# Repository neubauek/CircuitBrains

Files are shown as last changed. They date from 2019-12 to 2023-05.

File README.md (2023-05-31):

# CircuitBrains

## Deluxe
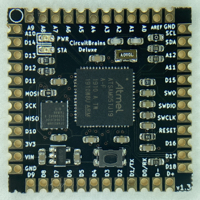
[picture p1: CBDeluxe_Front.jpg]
Deluxe Front
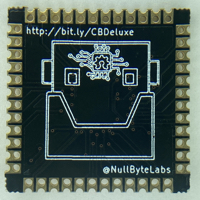
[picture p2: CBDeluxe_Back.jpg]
Deluxe Back
<br/>
https://kevinneubauer.com/projects/circuitbrains-deluxe/

Small form-factor 48-pin castellated pad module. Designed to allow an easy implementation of CircuitPython in maker/hacker projects without the bulk of a large breakout board.

Specs:
- Atmel ATSAMD51J19A Microcontroller (32-bit ARM Cortex M4)
- 8 MB SPI Flash
- Onboard 3.3V LDO Regulator
- Power and Status LEDs
- Breakouts for SPI and I2C
- Breakouts for 13 Analog and 19 Digital Inputs/Outputs

Revision History / Known Issues:

v1.0:
- Initial release
- Analog output does no work due to silicon issue with ATSAMD51. Requires a dedicated VREF/AREF pin with external 3.3 VREF input

v1.1 & v1.2:
- Not released due to issues resulting from design changes. I removed the pull-up on RST because the datasheet says it was optional. Turns out it was not so optional. These revisions will not function without a 10K resistor bodged onto the RST line.
- Dedicated a pin to VREF. Added a 0 Ohm resistor with a 3.3v input into VREF. 
- Switched from 4 layer to 2 layer board layout
- Rearranged layout to allow for pad documentation
- Added silkscreen for pad/pin assignments
- Added logo
- Removed inductor on VSW. Board will only work on linear power mode due to this.
- Removed polyfuse. Acceptable risk tradeoff for the space. If you want a fuse, add it to your design that incorporates this board.
- Removed Schottkey diode on VIN. Acceptable risk tradeoff for the space.
- Changed to a different flash chip with a smaller footprint
- Shuffled I/O pin assignments for more efficient trace routing/layout

v1.3:
- Added 10k pull-up back to RST.
- All tests working out: I2C, SPI, Analog & Digital In, Analog Out

## Basic
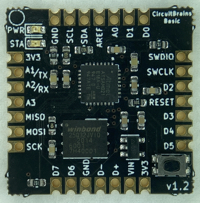
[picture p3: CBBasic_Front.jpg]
Basic Front
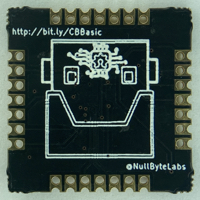
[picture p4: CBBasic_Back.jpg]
Basic Back
<br/>
https://kevinneubauer.com/projects/circuitbrains-basic/

Small form-factor 28-pin castellated pad module. Designed to allow an easy implementation of CircuitPython in maker/hacker projects without the bulk of a large breakout board.

Specs:
- Atmel ATSAMD21E18A Microcontroller (32-bit ARM Cortex M0)
- 4 MB SPI Flash
- Onboard 3.3V LDO Regulator
- Power and Status LEDs
- Breakouts for SPI and I2C
- Breakouts for 4 Analog and 8 Digital Inputs/Outputs

Revision History / Known Issues:
v1.2:
- Initial Release
- All tests working out

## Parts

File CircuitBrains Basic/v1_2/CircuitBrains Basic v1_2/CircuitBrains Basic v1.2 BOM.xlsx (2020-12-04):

Reference(s) | Value | Manufacturer | Part | Qty
C1, C4, C7 | 1uF | Yageo | CC0603KRX5R8BB105 | 3
C2, C3, C5, C6 | 0.1uF | Yageo | CC0603JRX7R9BB104 | 4
C8, C9 | 10uF | Murata | GRM188R61E106KA73D | 2
LED1 | GREEN | Würth Elektronik | 150060VS75000 | 1
LED2 | RED | Würth Elektronik | 150060RS75000 | 1
R1 | 100K | Yageo | RC0603FR-07100KL | 1
R3 | 330 | Yageo | RC0603FR-07330RL | 1
R4, R6 | 10K | Yageo | RC0603FR-0710KL | 2
R5, R7, R8 | 1K | Yageo | RC0603FR-071KL | 3
SW1 | KMR231 | C&K | KMR231NG LFS | 1
U1 | W25Q32JVZPIQ | Winbond Electronics | W25Q32JVZPIQ | 1
U2 | AP2112K-3.3 | Diodes Incorporated | AP2112K-3.3TRG1 | 1
U3 | ATSAMD21E18A-MU | Microchip Technology | ATSAMD21E18A-MU | 1

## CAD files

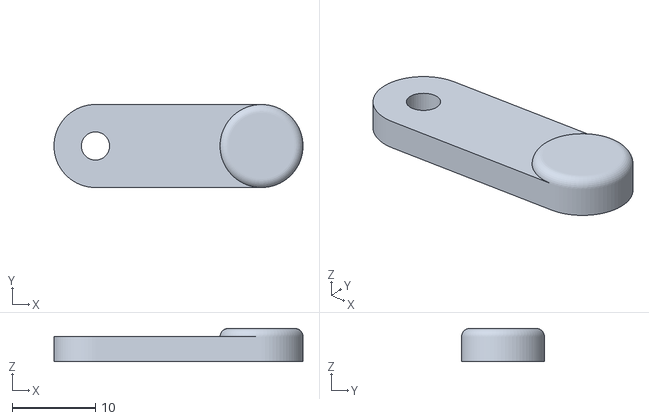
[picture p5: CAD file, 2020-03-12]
Test Jigs/3D Prints/CBJigArm.stl
30.0 x 10.0 x 4.00

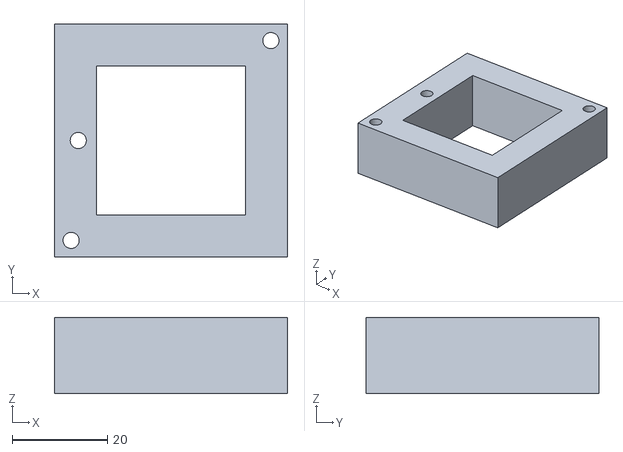
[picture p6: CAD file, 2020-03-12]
Test Jigs/3D Prints/CBDeluxeJigBlock.stl
49.0 x 49.0 x 16.0

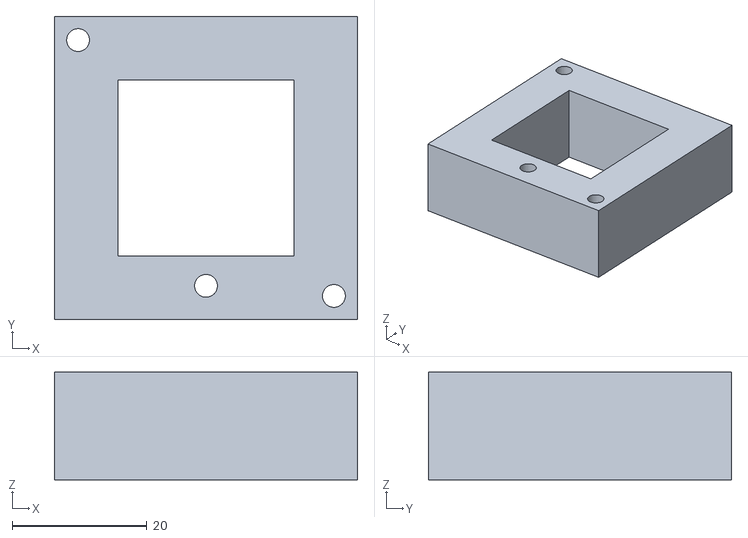
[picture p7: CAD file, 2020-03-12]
Test Jigs/3D Prints/CBBasicJigBlock.stl
45.0 x 45.0 x 16.0

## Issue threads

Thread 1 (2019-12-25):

Create PDF Schematic

nevvkid, 2019-12-25:
Hi @neubauek , just found this - awesome project. Doing a lot with SAMD51 MCUs myself. For example: https://github.com/dadamachines/doppler
Would be nice if you could add the schematic as PDF to the repository.
Cheers, J

neubauek, 2019-12-25:
Hello @nevvkid. Thanks for the feedback and awesome work on your FPGA stick! I do think a PDF schematic would make sense along with additional graphics and documentation on the pinout. However, I'm going through some changes in the design right now. Once I test them, I will upload the new design and will include a PDF. Leaving this issue open until then as a reminder.

nevvkid, 2019-12-25:
@neubauek Thanks! Let me know if you want to bounce ideas for the next revision.
And thanks for following on Twitter.
Send you a couple of DMs. Cheers, J

neubauek, 2019-12-30:
PDF schematic added with v1.3 update.

Closed 2019-12-30.

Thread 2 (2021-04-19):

Pages on your site are currently not working

Qqwy, 2021-04-19:
Hi there!

I wanted to look at the project in more detail by visiting https://www.kevinneubauer.com/portfolio/circuitbrains-deluxe/ but it currently spouts a 404 status code at me, so I thought I'd let you know :-).

neubauek, 2021-04-19:
Thank you for letting me know. Not sure how that happened but it is fixed now.

Closed 2021-04-19.

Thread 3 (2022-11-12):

Arduino SAMD51 board architecture

j3nsykes, 2022-11-12:
Hello,
What board architecture do you recommend for the SAMD51 chip on the CircuitBrain Deluxe if I want to use Arduino IDE not Circuit Python? I have tried the Adafruit Metro M4 which successfully uploads but the pin mapping differs. Do you support this or can you advise otherwise?

Thank you!

j3nsykes, 2022-11-14:
That's great thank you. I'm just in the process of craeting a custom board definition for it so will use these specs. I'll add a link to my Github with it once its finished so any other users can use it in Arduino.

One last question - Are the IO pins 5v tolerant or 3.3V (presuming 3.3V but just checking) and is the AREF 3.3V also or 5V?

Thank you.

neubauek, 2022-11-14:
All I/O is 3.3V. The only place you can supply 5V is through the VIN pin, which will route through the onboard regulator to power the ATSAMD51 at 3.3V. AREF is also max of 3.3V.

Regarding AREF, there was a silicon bug in the ATSAMD51 that disabled the DACs if AREF was not powered. It is the same bug mentioned on Adafruit's pages (https://learn.adafruit.com/adafruit-metro-m4-express-featuring-atsamd51?view=all). If you are fine with 3.3V AREF, you can disregard the rest of this.

The CircuitBrains Deluxe has AREF fixed at 3.3V by default. If you want to supply a different AREF voltage from off-board, you need to pull resistor R2. It is a 0 Ohm resistor. If you position the board such that AREF is in the upper right, R2 is the upper rightmost resistor. A thick chisel soldering iron tip should do the job if you don't have access to hot air. I apologize for the clunkiness of this, but it was the only way to work around a bug in the ATSAMD51 chip.

j3nsykes, 2022-11-14:
This is incredibly useful thank you!

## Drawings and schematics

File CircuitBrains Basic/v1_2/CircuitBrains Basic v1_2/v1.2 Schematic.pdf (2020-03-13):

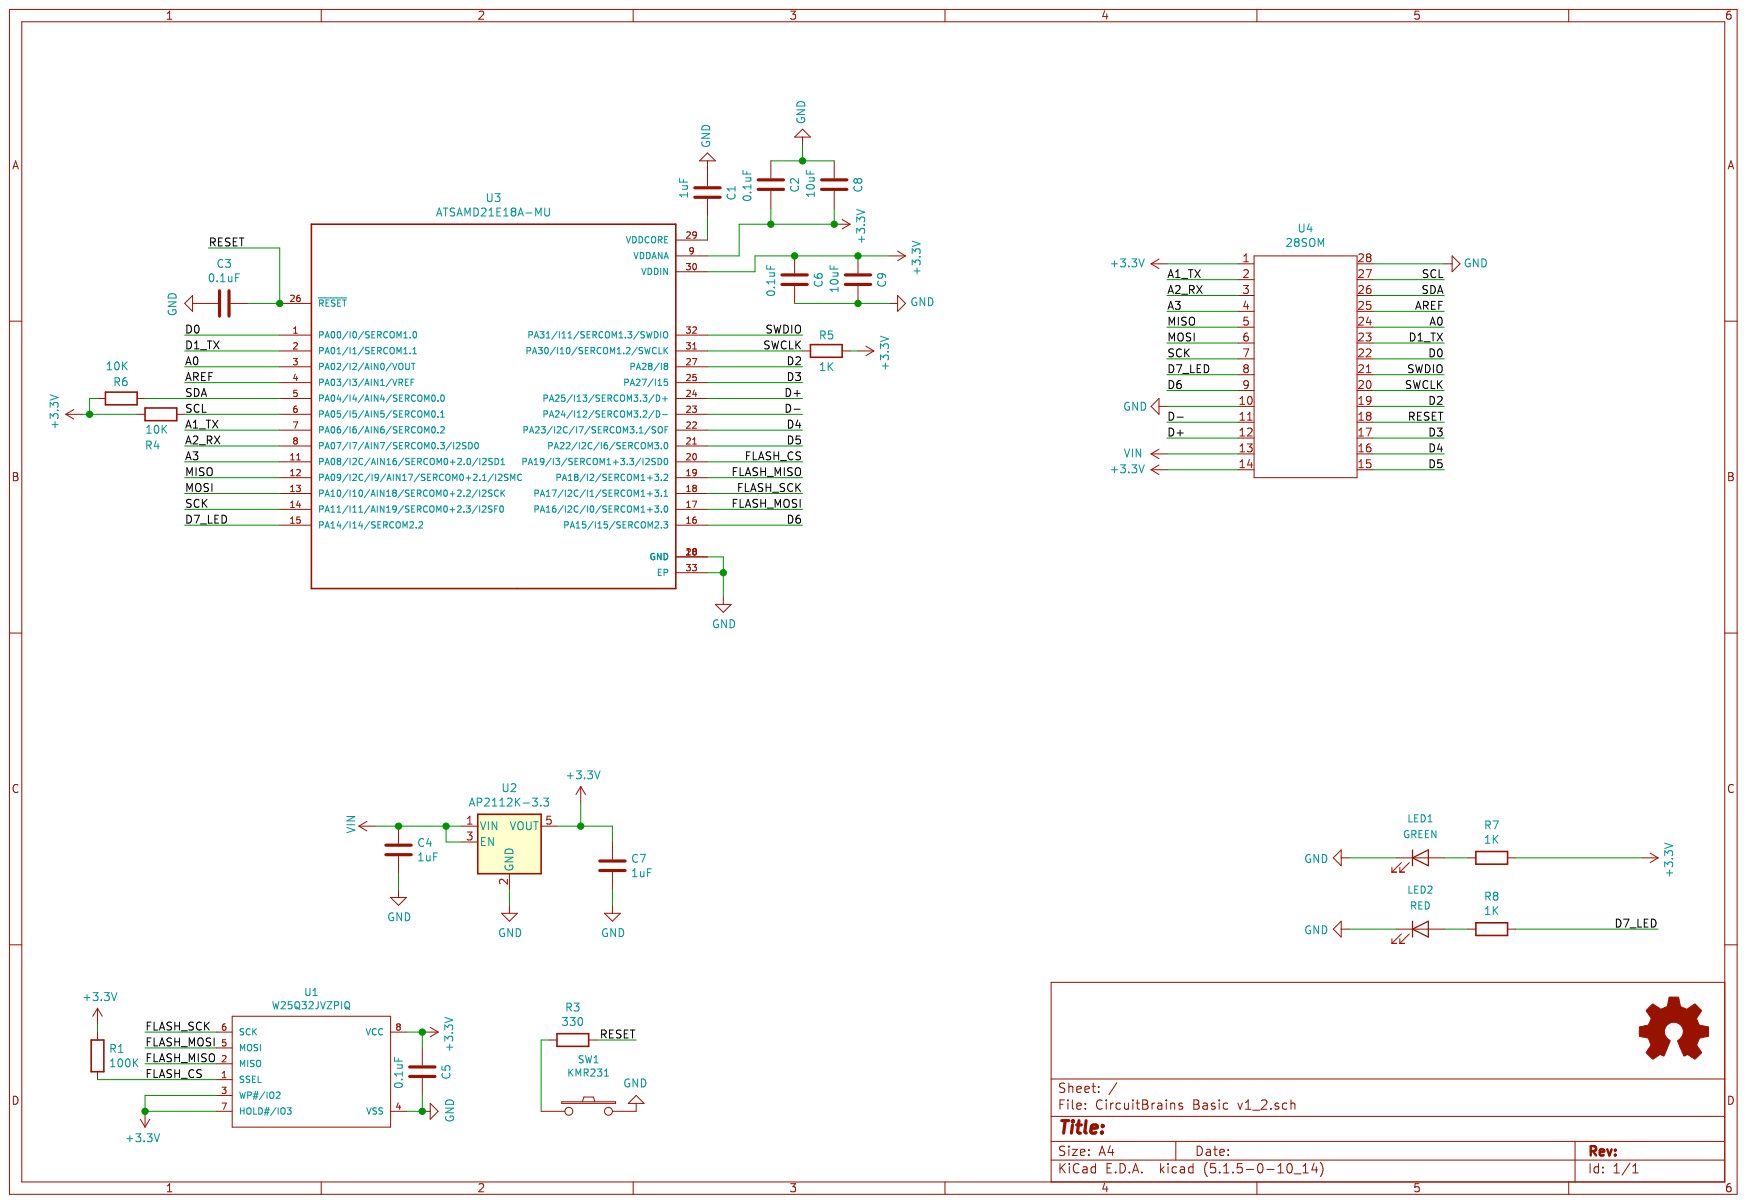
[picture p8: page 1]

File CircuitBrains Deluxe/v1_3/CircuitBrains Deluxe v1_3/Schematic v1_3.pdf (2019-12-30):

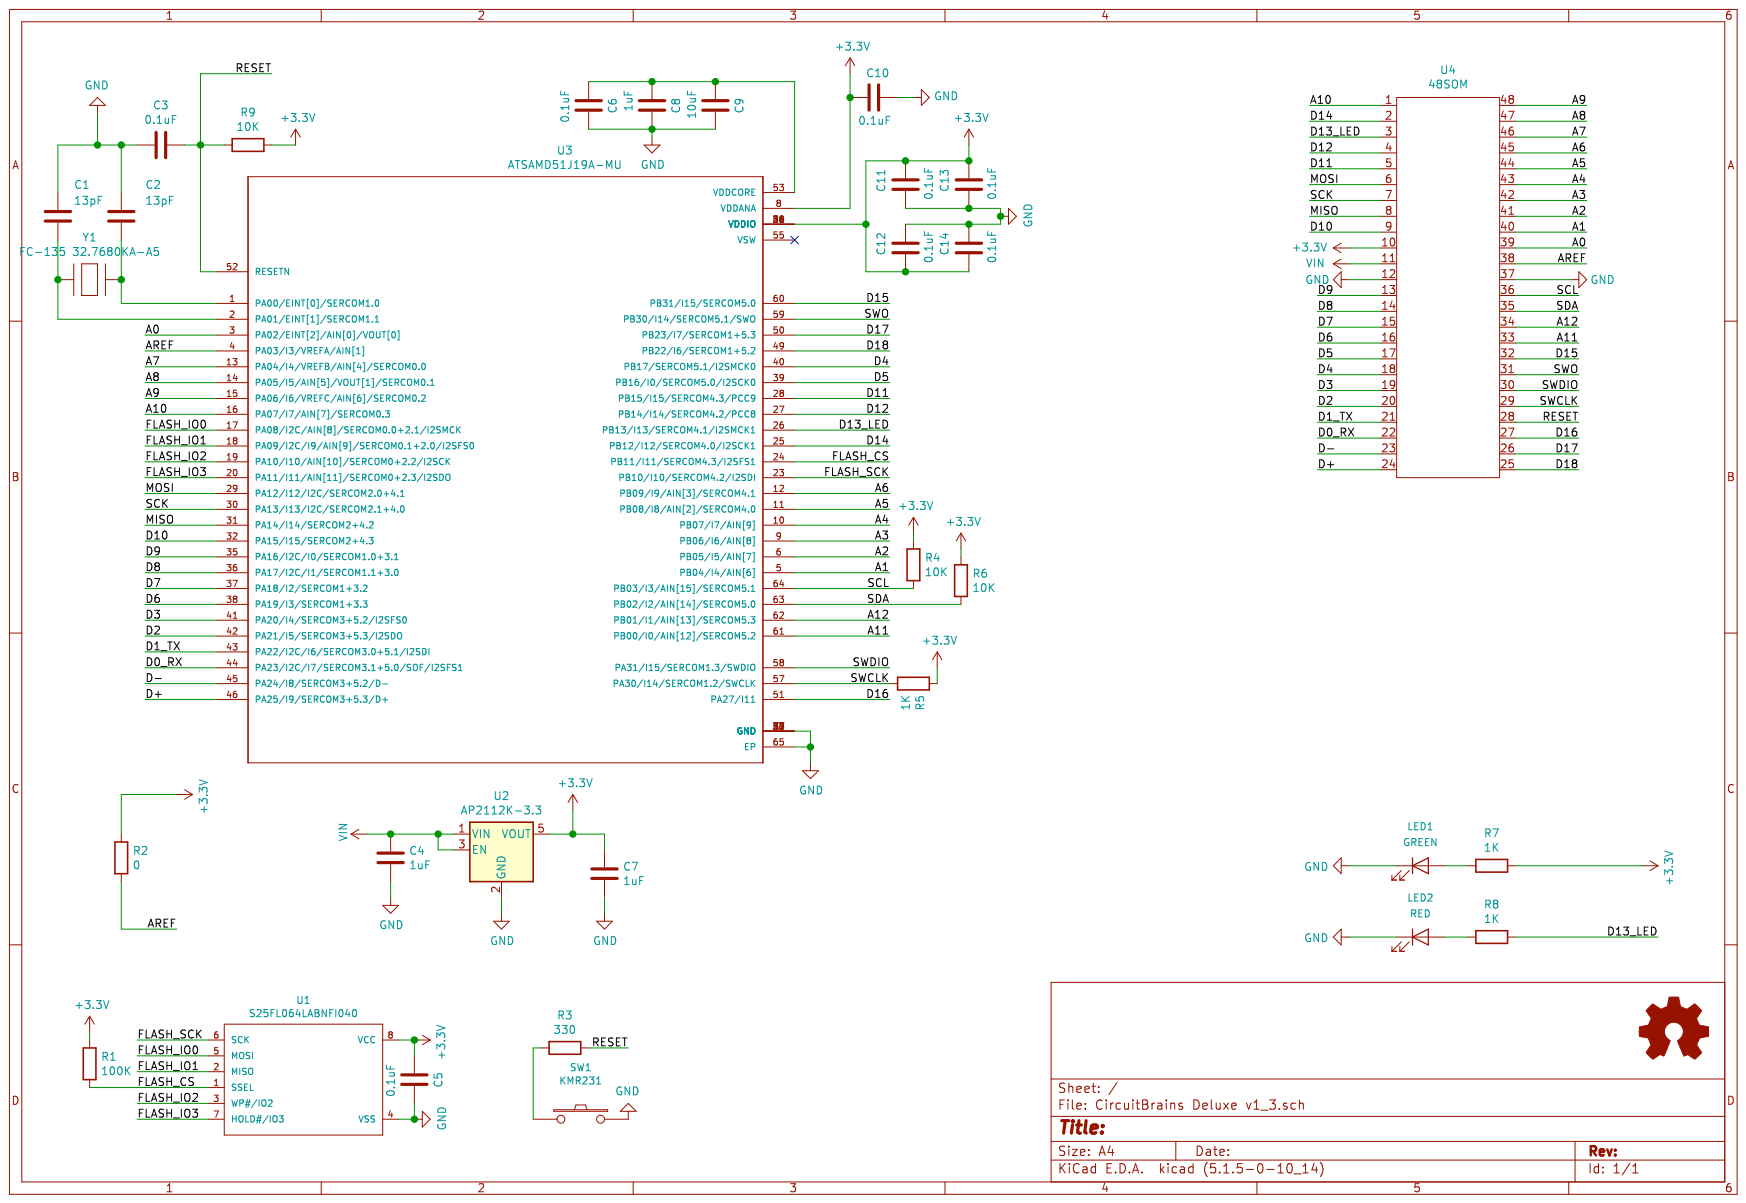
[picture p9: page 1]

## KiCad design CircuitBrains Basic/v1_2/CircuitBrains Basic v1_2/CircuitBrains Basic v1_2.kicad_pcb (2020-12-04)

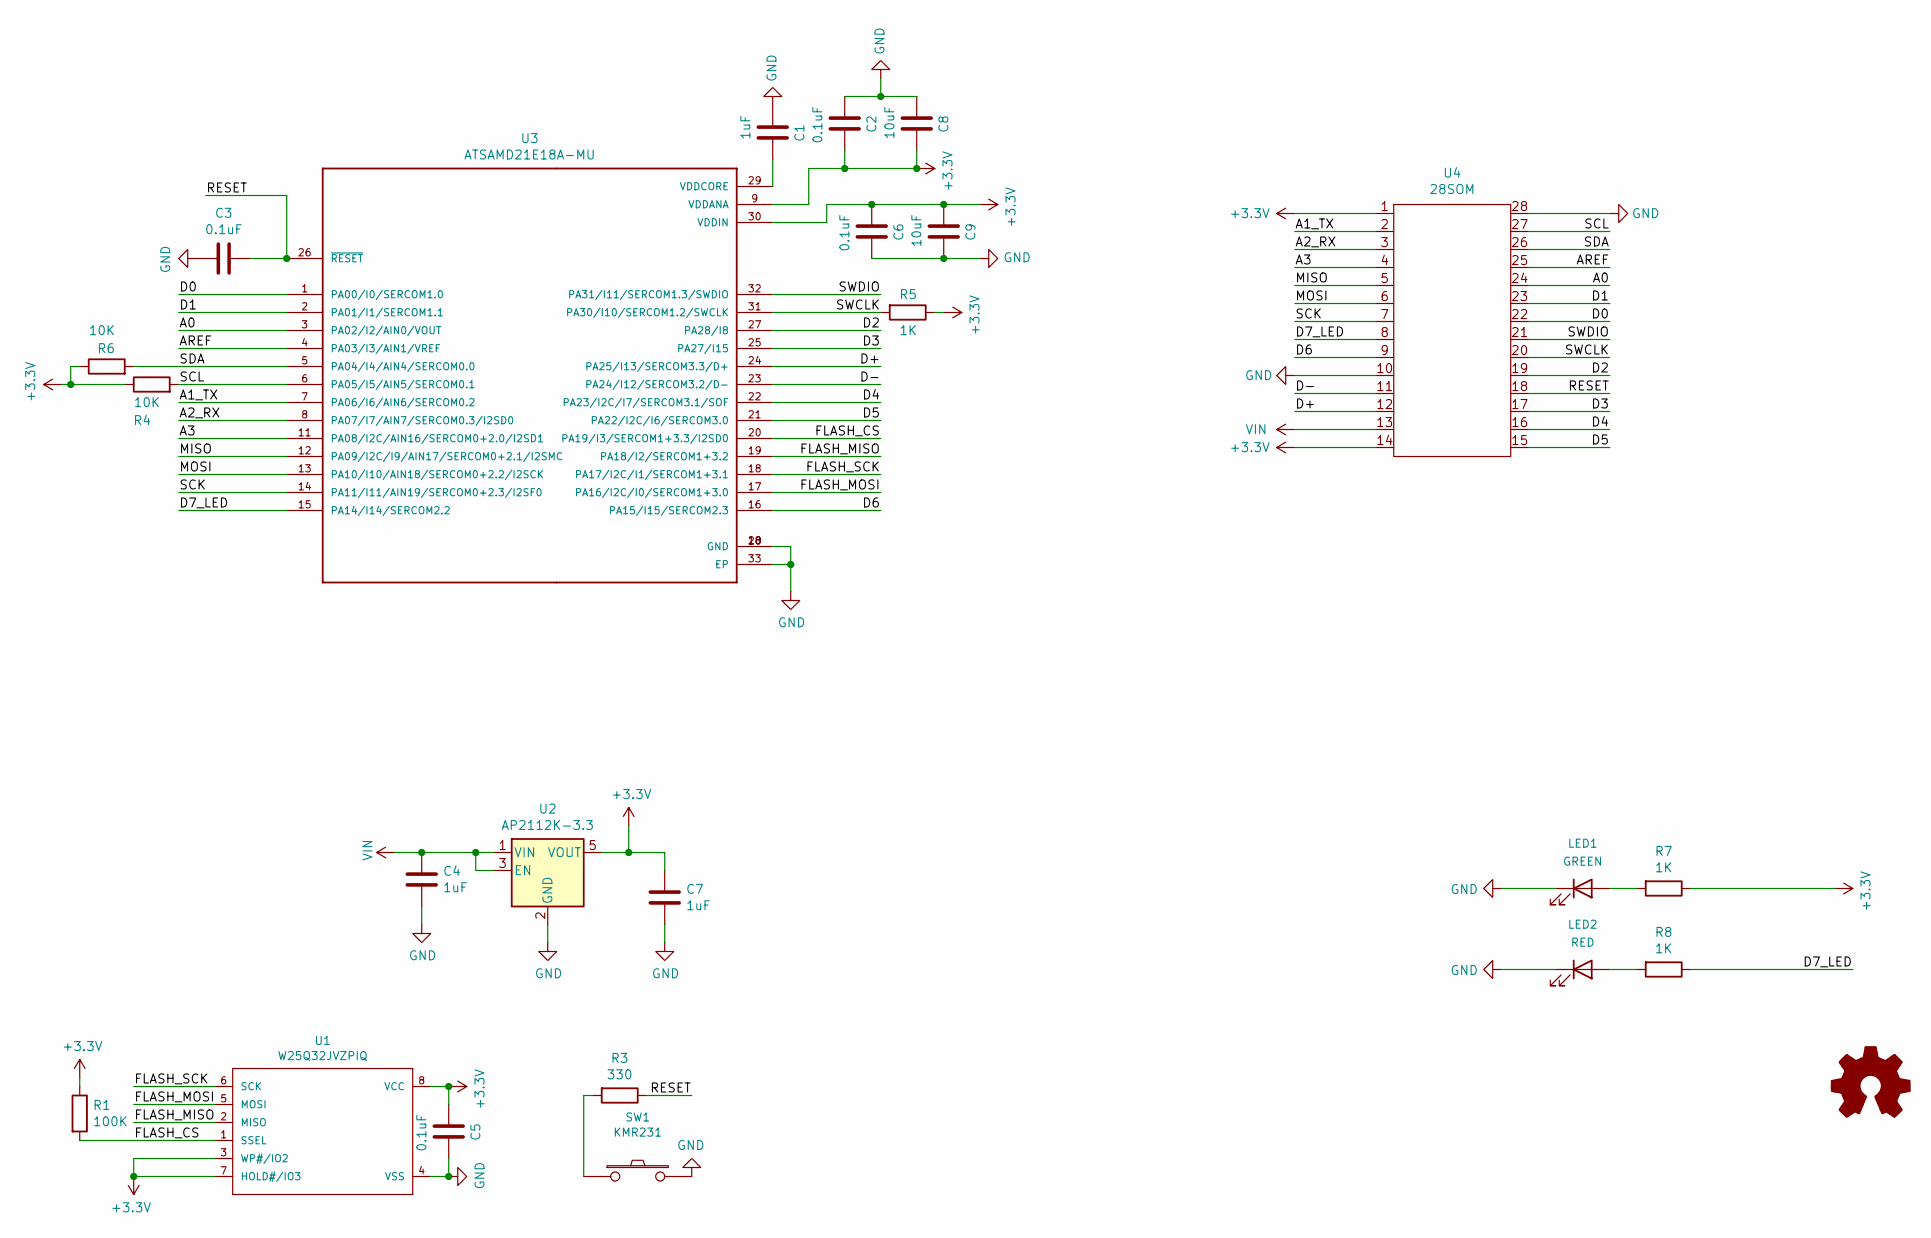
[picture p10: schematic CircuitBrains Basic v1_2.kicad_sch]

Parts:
C1, C4, C7: 1uF; C_0603_1608Metric
C2, C3, C5, C6: 0.1uF; C_0603_1608Metric
C8, C9: 10uF; C_0603_1608Metric
LED1: GREEN; LED_0603_1608Metric
LED2: RED; LED_0603_1608Metric
R1: 100K; R_0603_1608Metric
R3: 330; R_0603_1608Metric
R4, R6: 10K; R_0603_1608Metric
R5, R7, R8: 1K; R_0603_1608Metric
SW1: KMR231
U1: W25Q32JVZPIQ; WSON-8-1EP_6x5mm_P1.27mm_EP3.4x4.3mm
U2: AP2112K-3.3; SOT-23-5
U3: ATSAMD21E18A-MU; QFN50P500X500X100-33N
U4: 28SOM; 28SOM_25MMx25MM

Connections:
+3V3: C2.2, C5.1, C6.1, C7.1, C8.2, C9.1, R1.1, R4.1, R5.1, R6.1, R7.1, U1.3 (WP#/IO2), U1.7 (HOLD#/IO3), U1.8 (VCC), U2.5 (VOUT), U3.9 (VDDANA), U3.30 (VDDIN), U4.1, U4.14
/A0: U3.3 (PA02/I2/AIN0/VOUT), U4.24
/A1_TX: U3.7 (PA06/I6/AIN6/SERCOM0.2), U4.2
/A2_RX: U3.8 (PA07/I7/AIN7/SERCOM0.3/I2SD0), U4.3
/A3: U3.11 (PA08/I2C/AIN16/SERCOM0+2.0/I2SD1), U4.4
/AREF: U3.4 (PA03/I3/AIN1/VREF), U4.25
/D0: U3.1 (PA00/I0/SERCOM1.0), U4.22
/D1: U3.2 (PA01/I1/SERCOM1.1), U4.23
/D2: U3.27 (PA28/I8), U4.19
/D3: U3.25 (PA27/I15), U4.17
/D4: U3.22 (PA23/I2C/I7/SERCOM3.1/SOF), U4.16
/D5: U3.21 (PA22/I2C/I6/SERCOM3.0), U4.15
/D6: U3.16 (PA15/I15/SERCOM2.3), U4.9
/D7_LED: R8.1, U3.15 (PA14/I14/SERCOM2.2), U4.8
/D+: U3.24 (PA25/I13/SERCOM3.3/D+), U4.12
/D-: U3.23 (PA24/I12/SERCOM3.2/D-), U4.11
/FLASH_CS: R1.2, U1.1 (SSEL), U3.20 (PA19/I3/SERCOM1+3.3/I2SD0)
/FLASH_MISO: U1.2 (MISO), U3.19 (PA18/I2/SERCOM1+3.2)
/FLASH_MOSI: U1.5 (MOSI), U3.17 (PA16/I2C/I0/SERCOM1+3.0)
/FLASH_SCK: U1.6 (SCK), U3.18 (PA17/I2C/I1/SERCOM1+3.1)
/MISO: U3.12 (PA09/I2C/I9/AIN17/SERCOM0+2.1/I2SMC), U4.5
/MOSI: U3.13 (PA10/I10/AIN18/SERCOM0+2.2/I2SCK), U4.6
/RESET: C3.1, R3.1, U3.26 (~RESET~), U4.18
/SCK: U3.14 (PA11/I11/AIN19/SERCOM0+2.3/I2SF0), U4.7
/SCL: R4.2, U3.6 (PA05/I5/AIN5/SERCOM0.1), U4.27
/SDA: R6.2, U3.5 (PA04/I4/AIN4/SERCOM0.0), U4.26
/SWCLK: R5.2, U3.31 (PA30/I10/SERCOM1.2/SWCLK), U4.20
/SWDIO: U3.32 (PA31/I11/SERCOM1.3/SWDIO), U4.21
GND: C1.1, C2.1, C3.2, C4.2, C5.2, C6.2, C7.2, C8.1, C9.2, LED1.1 (K), LED2.1 (K), SW1.2, U1.4 (VSS), U2.2 (GND), U3.10 (GND), U3.28 (GND), U3.33 (EP), U4.10, U4.28
unnamed: C1.2, U3.29 (VDDCORE)
unnamed: LED1.2 (A), R7.2
unnamed: LED2.2 (A), R8.2
unnamed: R3.2, SW1.1
VIN: C4.1, U2.1 (VIN), U2.3 (EN), U4.13

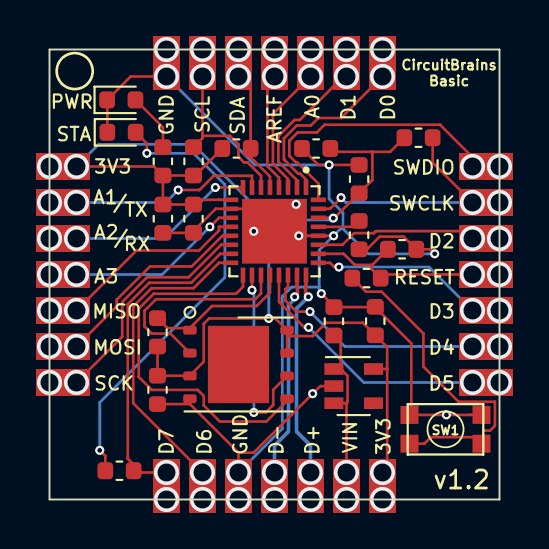
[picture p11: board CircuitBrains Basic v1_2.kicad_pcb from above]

Board: 2 copper layers, 25.0 x 25.0 mm, 23 parts (0 on the bottom side), 34 nets.

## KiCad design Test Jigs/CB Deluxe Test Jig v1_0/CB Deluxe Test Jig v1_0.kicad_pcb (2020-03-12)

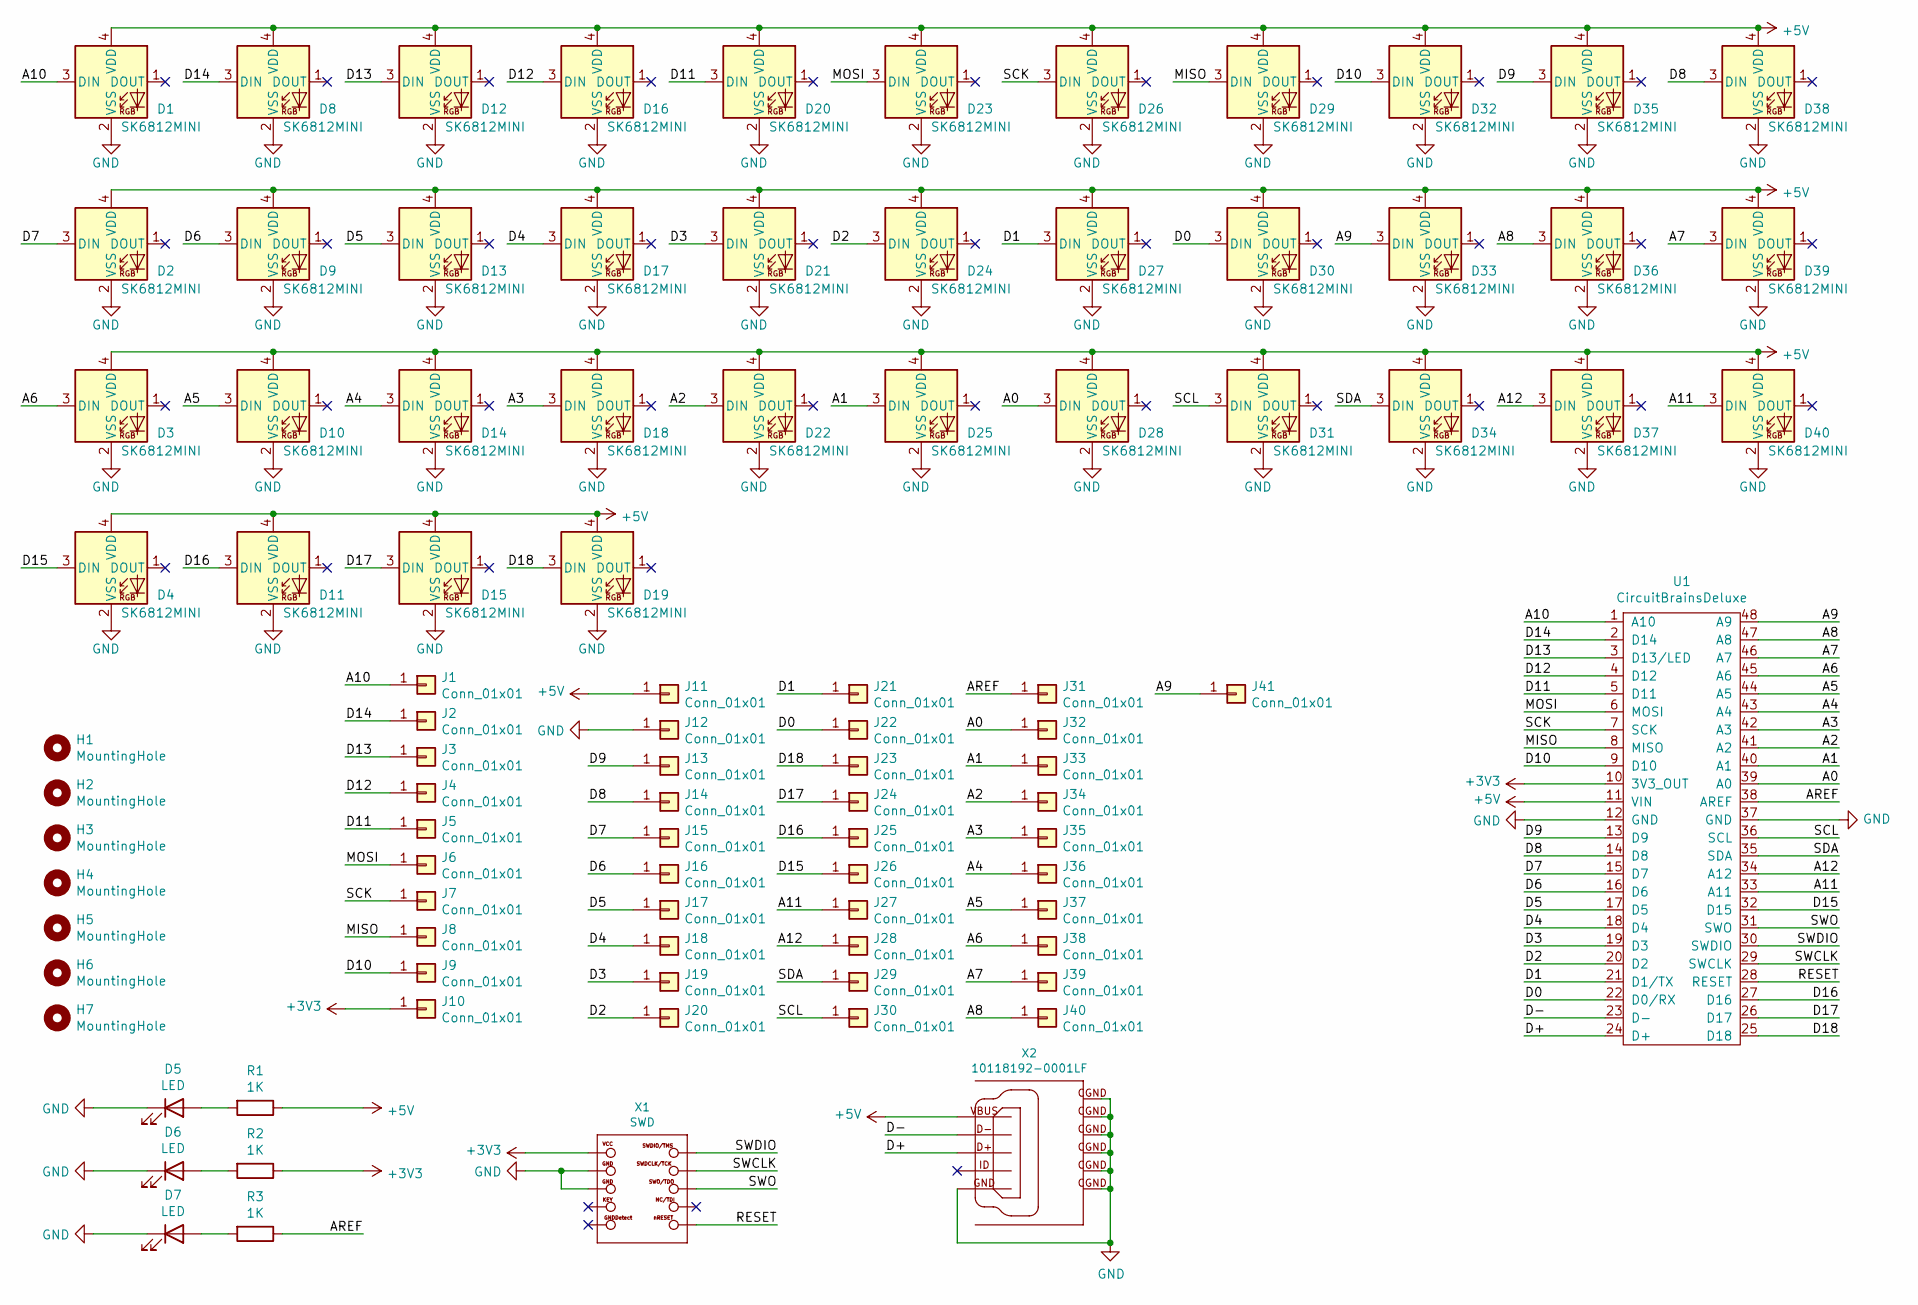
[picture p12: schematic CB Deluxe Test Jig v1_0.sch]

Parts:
D1, D2, D3, D4, D8, D9, D10, D11, D12, D13, D14, D15, D16, D17, D18, D19, D20, D21, D22, D23, D24, D25, D26, D27, D28, D29, D30, D31, D32, D33, D34, D35, D36, D37, D38, D39, D40: SK6812MINI; SK6812_Mini
D5, D6, D7: LED; LED_0805_2012Metric_Pad1.15x1.40mm_HandSolder
H1, H2, H3, H4, H5, H6, H7: MountingHole; MountingHole_3.2mm_M3
J1, J2, J3, J4, J5, J6, J7, J8, J9, J10, J11, J12, J13, J14, J15, J16, J17, J18, J19, J20, J21, J22, J23, J24, J25, J26, J27, J28, J29, J30, J31, J32, J33, J34, J35, J36, J37, J38, J39, J40, J41: Conn_01x01; PinHeader_1x01_P2.54mm_Vertical
R1, R2, R3: 1K; R_0805_2012Metric_Pad1.15x1.40mm_HandSolder
U1: CircuitBrainsDeluxe; Deluxe_48SOM_29MMx29MM_Pogo_Test_Jig
X1: SWD; 2X05_1.27MM_BOX_POSTS_SMT
X2: 10118192-0001LF; 10118192-0001LF(MICRO-USB-B-AMPHENOL-FCI)

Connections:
+3V3: J10.1, R2.1, U1.10 (3V3_OUT), X1.1 (VCC)
+5V: D1.4 (VDD), D2.4 (VDD), D3.4 (VDD), D4.4 (VDD), D8.4 (VDD), D9.4 (VDD), D10.4 (VDD), D11.4 (VDD), D12.4 (VDD), D13.4 (VDD), D14.4 (VDD), D15.4 (VDD), D16.4 (VDD), D17.4 (VDD), D18.4 (VDD), D19.4 (VDD), D20.4 (VDD), D21.4 (VDD), D22.4 (VDD), D23.4 (VDD), D24.4 (VDD), D25.4 (VDD), D26.4 (VDD), D27.4 (VDD), D28.4 (VDD), D29.4 (VDD), D30.4 (VDD), D31.4 (VDD), D32.4 (VDD), D33.4 (VDD), D34.4 (VDD), D35.4 (VDD), D36.4 (VDD), D37.4 (VDD), D38.4 (VDD), D39.4 (VDD), D40.4 (VDD), J11.1, R1.1, U1.11 (VIN), X2.VBUS
/A0: D28.3 (DIN), J32.1, U1.39 (A0)
/A1: D25.3 (DIN), J33.1, U1.40 (A1)
/A2: D22.3 (DIN), J34.1, U1.41 (A2)
/A3: D18.3 (DIN), J35.1, U1.42 (A3)
/A4: D14.3 (DIN), J36.1, U1.43 (A4)
/A5: D10.3 (DIN), J37.1, U1.44 (A5)
/A6: D3.3 (DIN), J38.1, U1.45 (A6)
/A7: D39.3 (DIN), J39.1, U1.46 (A7)
/A8: D36.3 (DIN), J40.1, U1.47 (A8)
/A9: D33.3 (DIN), J41.1, U1.48 (A9)
/A10: D1.3 (DIN), J1.1, U1.1 (A10)
/A11: D40.3 (DIN), J27.1, U1.33 (A11)
/A12: D37.3 (DIN), J28.1, U1.34 (A12)
/AREF: J31.1, R3.1, U1.38 (AREF)
/D0: D30.3 (DIN), J22.1, U1.22 (D0/RX)
/D1: D27.3 (DIN), J21.1, U1.21 (D1/TX)
/D2: D24.3 (DIN), J20.1, U1.20 (D2)
/D3: D21.3 (DIN), J19.1, U1.19 (D3)
/D4: D17.3 (DIN), J18.1, U1.18 (D4)
/D5: D13.3 (DIN), J17.1, U1.17 (D5)
/D6: D9.3 (DIN), J16.1, U1.16 (D6)
/D7: D2.3 (DIN), J15.1, U1.15 (D7)
/D8: D38.3 (DIN), J14.1, U1.14 (D8)
/D9: D35.3 (DIN), J13.1, U1.13 (D9)
/D10: D32.3 (DIN), J9.1, U1.9 (D10)
/D11: D20.3 (DIN), J5.1, U1.5 (D11)
/D12: D16.3 (DIN), J4.1, U1.4 (D12)
/D13: D12.3 (DIN), J3.1, U1.3 (D13/LED)
/D14: D8.3 (DIN), J2.1, U1.2 (D14)
/D15: D4.3 (DIN), J26.1, U1.32 (D15)
/D16: D11.3 (DIN), J25.1, U1.27 (D16)
/D17: D15.3 (DIN), J24.1, U1.26 (D17)
/D18: D19.3 (DIN), J23.1, U1.25 (D18)
/D+: U1.24 (D+), X2.D+
/D-: U1.23 (D-), X2.D-
/MISO: D29.3 (DIN), J8.1, U1.8 (MISO)
/MOSI: D23.3 (DIN), J6.1, U1.6 (MOSI)
/RESET: U1.28 (RESET), X1.10 (NRESET)
/SCK: D26.3 (DIN), J7.1, U1.7 (SCK)
/SCL: D31.3 (DIN), J30.1, U1.36 (SCL)
/SDA: D34.3 (DIN), J29.1, U1.35 (SDA)
/SWCLK: U1.29 (SWCLK), X1.4 (SWDCLK)
/SWDIO: U1.30 (SWDIO), X1.2 (SWDIO)
/SWO: U1.31 (SWO), X1.6 (SWO)
GND: D1.2 (VSS), D2.2 (VSS), D3.2 (VSS), D4.2 (VSS), D5.1 (K), D6.1 (K), D7.1 (K), D8.2 (VSS), D9.2 (VSS), D10.2 (VSS), D11.2 (VSS), D12.2 (VSS), D13.2 (VSS), D14.2 (VSS), D15.2 (VSS), D16.2 (VSS), D17.2 (VSS), D18.2 (VSS), D19.2 (VSS), D20.2 (VSS), D21.2 (VSS), D22.2 (VSS), D23.2 (VSS), D24.2 (VSS), D25.2 (VSS), D26.2 (VSS), D27.2 (VSS), D28.2 (VSS), D29.2 (VSS), D30.2 (VSS), D31.2 (VSS), D32.2 (VSS), D33.2 (VSS), D34.2 (VSS), D35.2 (VSS), D36.2 (VSS), D37.2 (VSS), D38.2 (VSS), D39.2 (VSS), D40.2 (VSS), J12.1, U1.12 (GND), U1.37 (GND), X1.3 (GND), X1.5 (GND), X2.CGND (SGND1), X2.GND
unnamed: D5.2 (A), R1.2
unnamed: D6.2 (A), R2.2
unnamed: D7.2 (A), R3.2

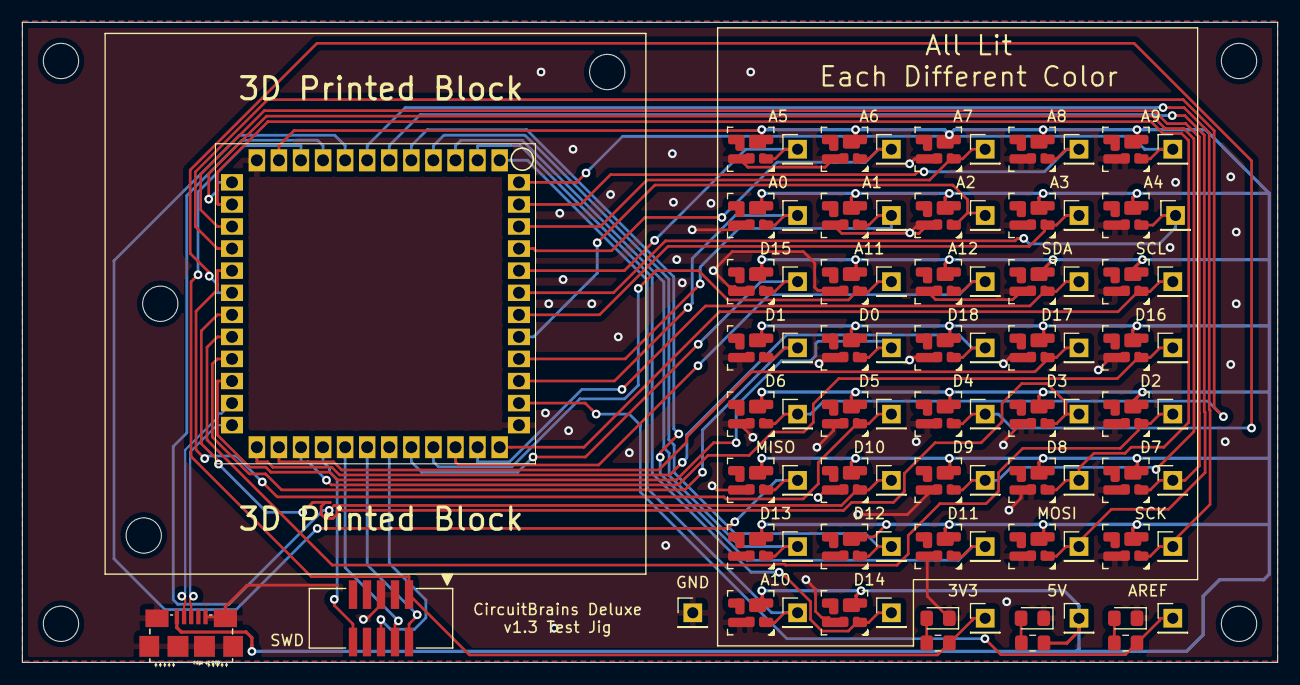
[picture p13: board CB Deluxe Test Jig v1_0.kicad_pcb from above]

Board: 2 copper layers, 113.8 x 58.0 mm, 94 parts (0 on the bottom side), 50 nets.

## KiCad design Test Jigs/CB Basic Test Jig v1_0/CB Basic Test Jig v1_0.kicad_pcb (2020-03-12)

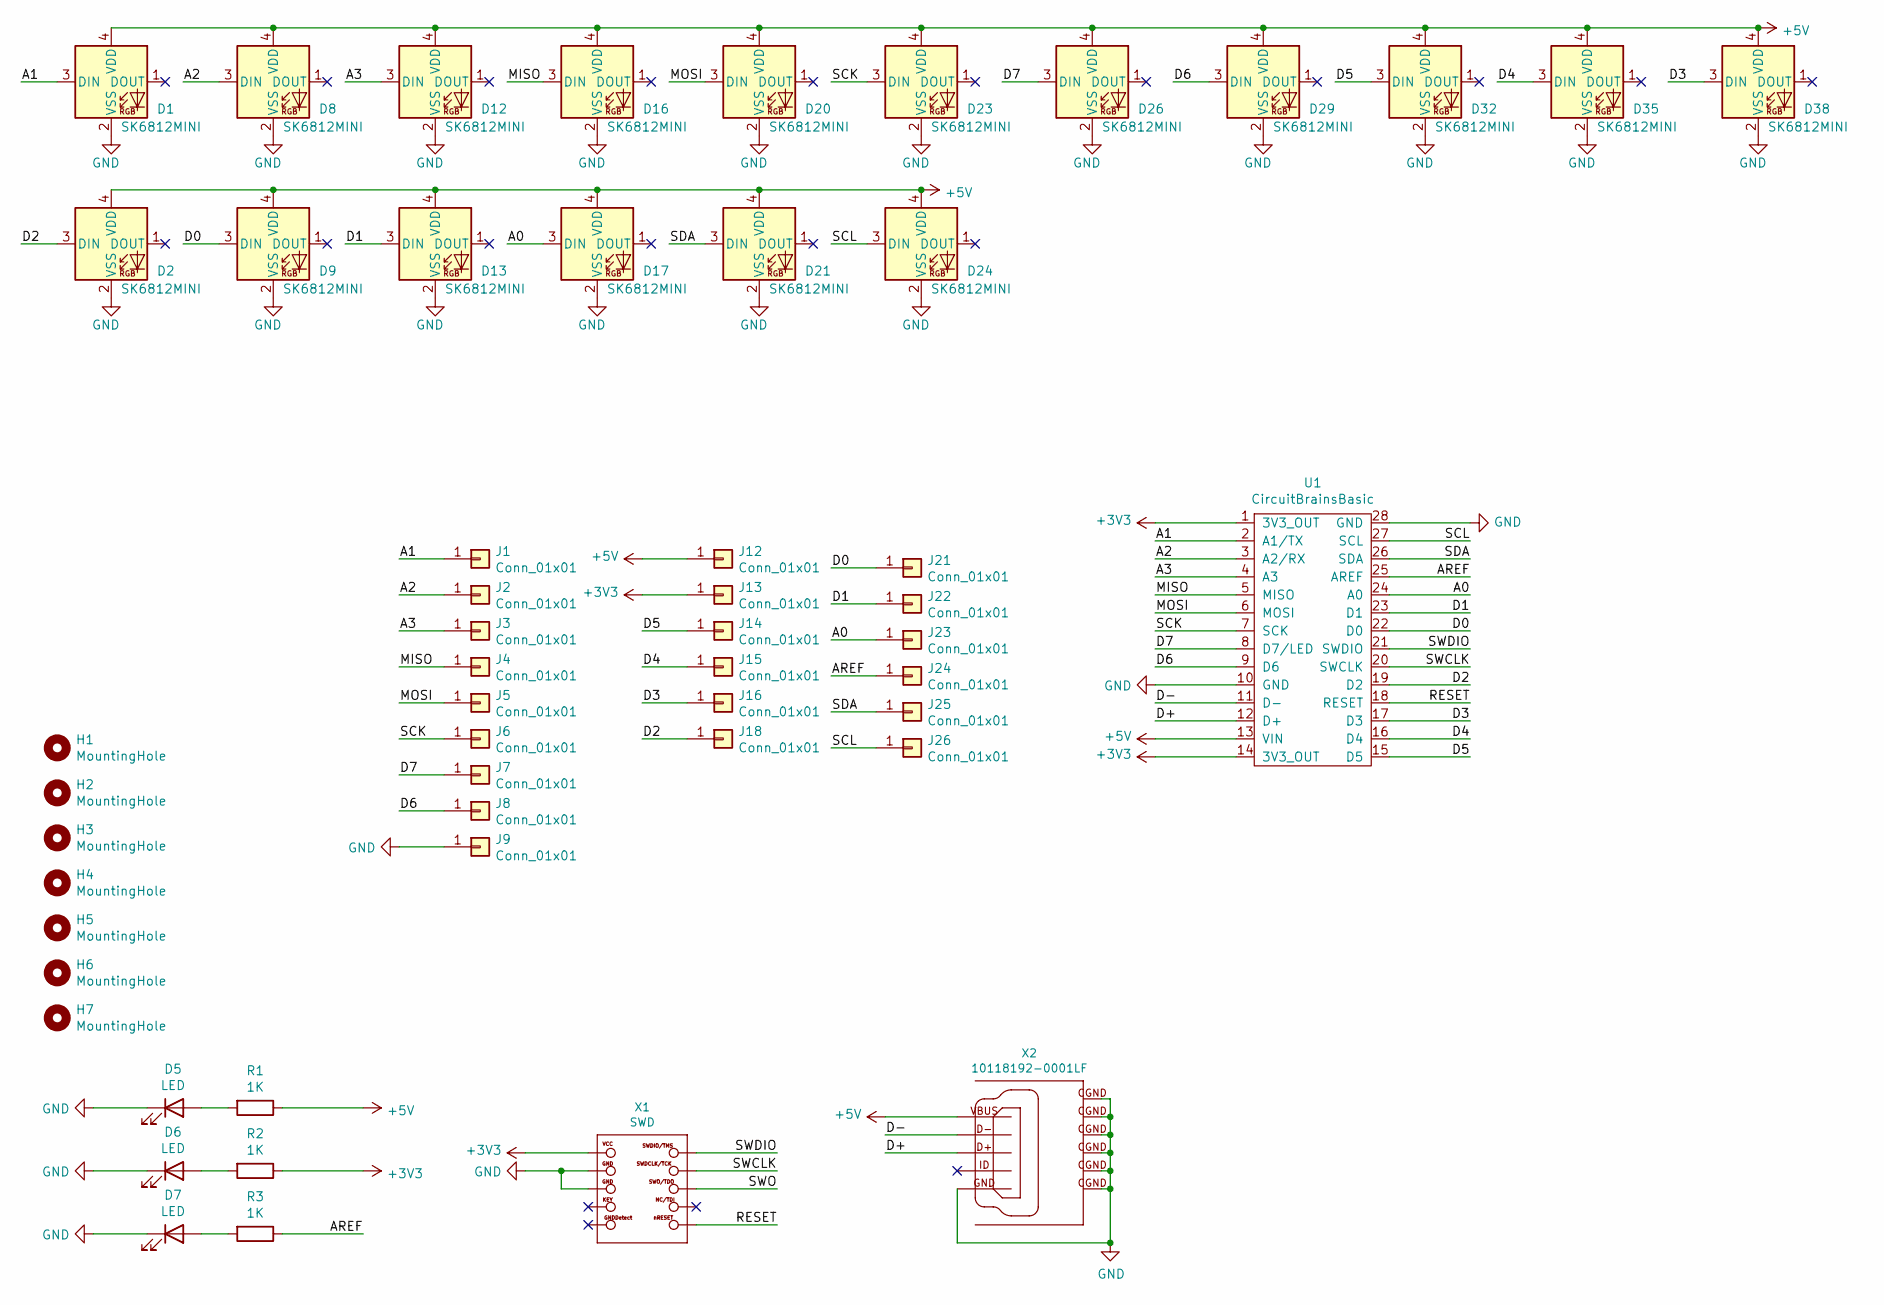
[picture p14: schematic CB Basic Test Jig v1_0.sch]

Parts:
D1, D2, D8, D9, D12, D13, D16, D17, D20, D21, D23, D24, D26, D29, D32, D35, D38: SK6812MINI; SK6812_Mini
D5, D6, D7: LED; LED_0805_2012Metric_Pad1.15x1.40mm_HandSolder
H1, H2, H3, H4, H5, H6, H7: MountingHole; MountingHole_3.2mm_M3
J1, J2, J3, J4, J5, J6, J7, J8, J9, J12, J13, J14, J15, J16, J18, J21, J22, J23, J24, J25, J26: Conn_01x01; PinHeader_1x01_P2.54mm_Vertical
R1, R2, R3: 1K; R_0805_2012Metric_Pad1.15x1.40mm_HandSolder
U1: CircuitBrainsBasic; Basic_28SOM_25MMx25MM_Pogo_Test_Jig
X1: SWD; 2X05_1.27MM_BOX_POSTS_SMT
X2: 10118192-0001LF; 10118192-0001LF(MICRO-USB-B-AMPHENOL-FCI)

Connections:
+3V3: J13.1, R2.1, U1.1 (3V3_OUT), U1.14 (3V3_OUT), X1.1 (VCC)
+5V: D1.4 (VDD), D2.4 (VDD), D8.4 (VDD), D9.4 (VDD), D12.4 (VDD), D13.4 (VDD), D16.4 (VDD), D17.4 (VDD), D20.4 (VDD), D21.4 (VDD), D23.4 (VDD), D24.4 (VDD), D26.4 (VDD), D29.4 (VDD), D32.4 (VDD), D35.4 (VDD), D38.4 (VDD), J12.1, R1.1, U1.13 (VIN), X2.VBUS
/A0: D17.3 (DIN), J23.1, U1.24 (A0)
/A1: D1.3 (DIN), J1.1, U1.2 (A1/TX)
/A2: D8.3 (DIN), J2.1, U1.3 (A2/RX)
/A3: D12.3 (DIN), J3.1, U1.4 (A3)
/AREF: J24.1, R3.1, U1.25 (AREF)
/D0: D9.3 (DIN), J21.1, U1.22 (D0)
/D1: D13.3 (DIN), J22.1, U1.23 (D1)
/D2: D2.3 (DIN), J18.1, U1.19 (D2)
/D3: D38.3 (DIN), J16.1, U1.17 (D3)
/D4: D35.3 (DIN), J15.1, U1.16 (D4)
/D5: D32.3 (DIN), J14.1, U1.15 (D5)
/D6: D29.3 (DIN), J8.1, U1.9 (D6)
/D7: D26.3 (DIN), J7.1, U1.8 (D7/LED)
/D+: U1.12 (D+), X2.D+
/D-: U1.11 (D-), X2.D-
/MISO: D16.3 (DIN), J4.1, U1.5 (MISO)
/MOSI: D20.3 (DIN), J5.1, U1.6 (MOSI)
/RESET: U1.18 (RESET), X1.10 (NRESET)
/SCK: D23.3 (DIN), J6.1, U1.7 (SCK)
/SCL: D24.3 (DIN), J26.1, U1.27 (SCL)
/SDA: D21.3 (DIN), J25.1, U1.26 (SDA)
/SWCLK: U1.20 (SWCLK), X1.4 (SWDCLK)
/SWDIO: U1.21 (SWDIO), X1.2 (SWDIO)
/SWO: X1.6 (SWO)
GND: D1.2 (VSS), D2.2 (VSS), D5.1 (K), D6.1 (K), D7.1 (K), D8.2 (VSS), D9.2 (VSS), D12.2 (VSS), D13.2 (VSS), D16.2 (VSS), D17.2 (VSS), D20.2 (VSS), D21.2 (VSS), D23.2 (VSS), D24.2 (VSS), D26.2 (VSS), D29.2 (VSS), D32.2 (VSS), D35.2 (VSS), D38.2 (VSS), J9.1, U1.10 (GND), U1.28 (GND), X1.3 (GND), X1.5 (GND), X2.CGND (SGND1), X2.GND
unnamed: D5.2 (A), R1.2
unnamed: D6.2 (A), R2.2
unnamed: D7.2 (A), R3.2

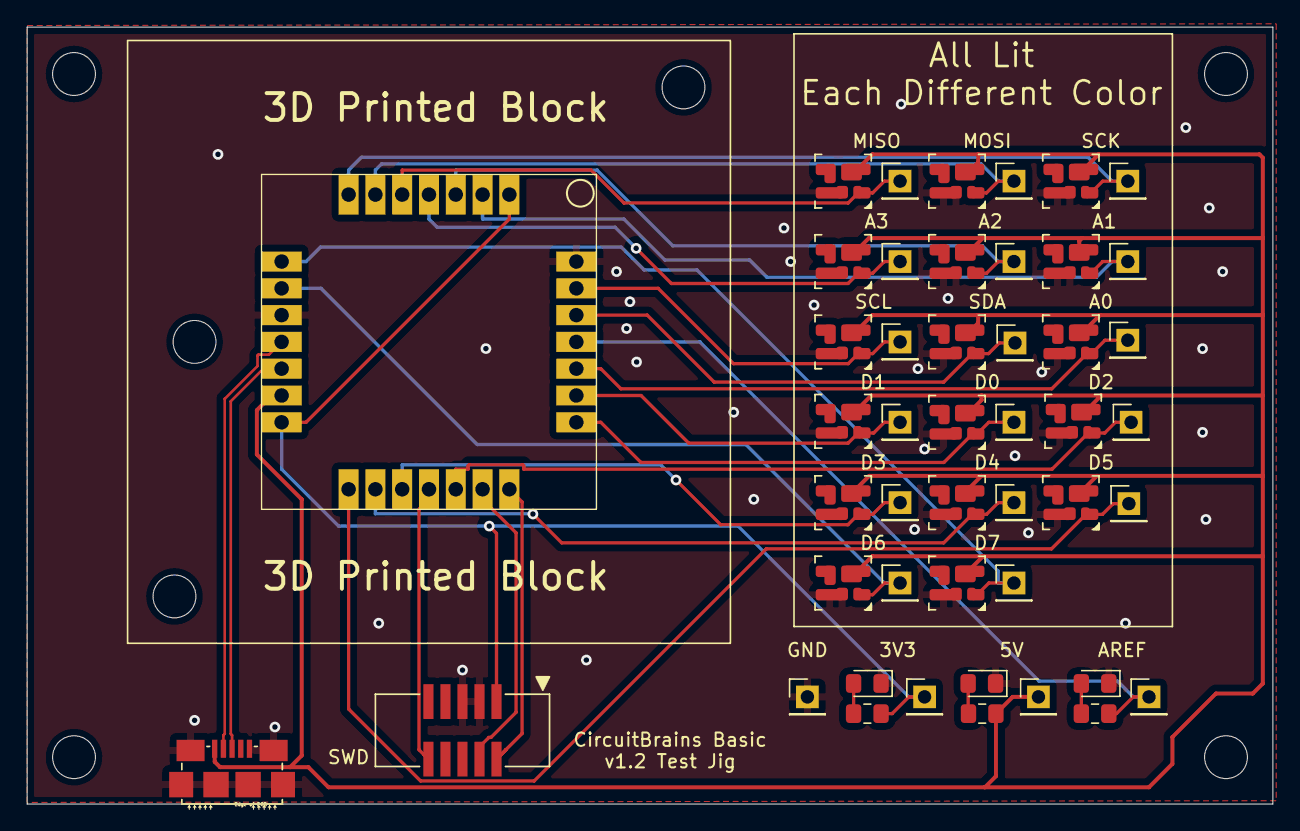
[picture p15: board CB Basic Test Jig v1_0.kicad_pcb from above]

Board: 2 copper layers, 93.0 x 58.0 mm, 54 parts (0 on the bottom side), 29 nets.

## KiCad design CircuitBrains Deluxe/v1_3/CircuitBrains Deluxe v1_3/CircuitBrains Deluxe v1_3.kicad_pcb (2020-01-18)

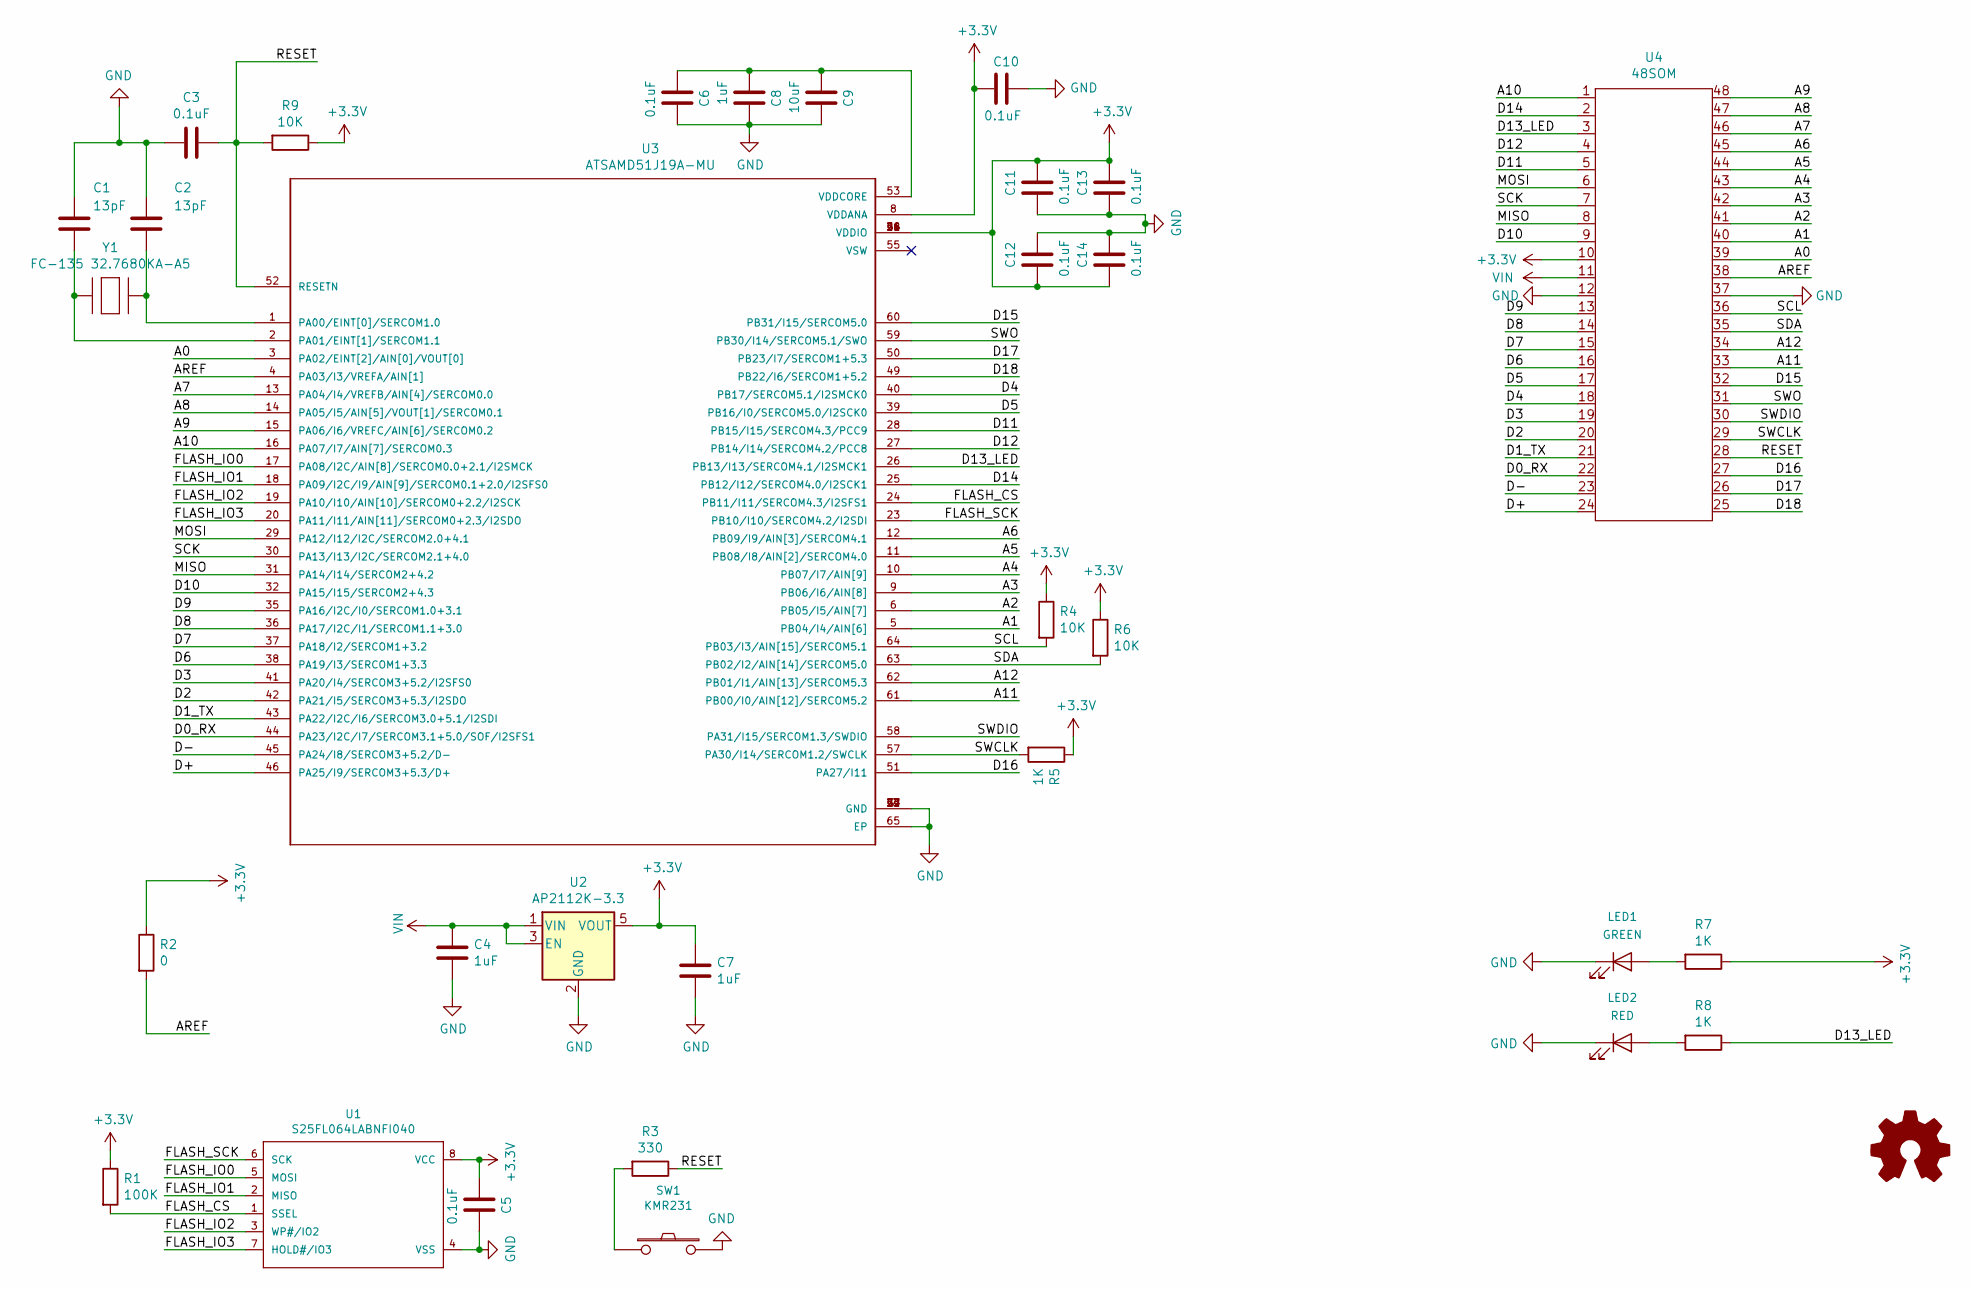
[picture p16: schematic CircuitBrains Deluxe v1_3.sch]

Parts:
C1, C2: 13pF; C_0603_1608Metric
C3, C5, C6, C10, C11, C12, C13, C14: 0.1uF; C_0603_1608Metric
C4, C7, C8: 1uF; C_0603_1608Metric
C9: 10uF; C_0603_1608Metric
LED1: GREEN; LED_0603_1608Metric
LED2: RED; LED_0603_1608Metric
R1: 100K; R_0603_1608Metric
R2: 0; R_0603_1608Metric
R3: 330; R_0603_1608Metric
R4, R6, R9: 10K; R_0603_1608Metric
R5, R7, R8: 1K; R_0603_1608Metric
SW1: KMR231
U1: S25FL064LABNFI040; WSON-8_4x4mm_P0.8mm
U2: AP2112K-3.3; SOT-23-5
U3: ATSAMD51J19A-MU; QFN64
U4: 48SOM; 48SOM_29MMx29MM
Y1: FC-135 32.7680KA-A5; XTAL3.2x1.5

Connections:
+3V3: C5.1, C7.1, C10.1, C11.2, C12.1, C13.2, C14.1, R1.1, R2.1, R4.1, R5.1, R6.1, R7.1, R9.1, U1.8 (VCC), U2.5 (VOUT), U3.8 (VDDANA), U3.21 (VDDIO), U3.34 (VDDIO), U3.48 (VDDIO), U3.56 (VDDIO), U4.10
/A0: U3.3 (PA02/EINT[2]/AIN[0]/VOUT[0]), U4.39
/A1: U3.5 (PB04/I4/AIN[6]), U4.40
/A2: U3.6 (PB05/I5/AIN[7]), U4.41
/A3: U3.9 (PB06/I6/AIN[8]), U4.42
/A4: U3.10 (PB07/I7/AIN[9]), U4.43
/A5: U3.11 (PB08/I8/AIN[2]/SERCOM4.0), U4.44
/A6: U3.12 (PB09/I9/AIN[3]/SERCOM4.1), U4.45
/A7: U3.13 (PA04/I4/VREFB/AIN[4]/SERCOM0.0), U4.46
/A8: U3.14 (PA05/I5/AIN[5]/VOUT[1]/SERCOM0.1), U4.47
/A9: U3.15 (PA06/I6/VREFC/AIN[6]/SERCOM0.2), U4.48
/A10: U3.16 (PA07/I7/AIN[7]/SERCOM0.3), U4.1
/A11: U3.61 (PB00/I0/AIN[12]/SERCOM5.2), U4.33
/A12: U3.62 (PB01/I1/AIN[13]/SERCOM5.3), U4.34
/AREF: R2.2, U3.4 (PA03/I3/VREFA/AIN[1]), U4.38
/D0_RX: U3.44 (PA23/I2C/I7/SERCOM3.1+5.0/SOF/I2SFS1), U4.22
/D1_TX: U3.43 (PA22/I2C/I6/SERCOM3.0+5.1/I2SDI), U4.21
/D2: U3.42 (PA21/I5/SERCOM3+5.3/I2SDO), U4.20
/D3: U3.41 (PA20/I4/SERCOM3+5.2/I2SFS0), U4.19
/D4: U3.40 (PB17/SERCOM5.1/I2SMCK0), U4.18
/D5: U3.39 (PB16/I0/SERCOM5.0/I2SCK0), U4.17
/D6: U3.38 (PA19/I3/SERCOM1+3.3), U4.16
/D7: U3.37 (PA18/I2/SERCOM1+3.2), U4.15
/D8: U3.36 (PA17/I2C/I1/SERCOM1.1+3.0), U4.14
/D9: U3.35 (PA16/I2C/I0/SERCOM1.0+3.1), U4.13
/D10: U3.32 (PA15/I15/SERCOM2+4.3), U4.9
/D11: U3.28 (PB15/I15/SERCOM4.3/PCC9), U4.5
/D12: U3.27 (PB14/I14/SERCOM4.2/PCC8), U4.4
/D13_LED: R8.1, U3.26 (PB13/I13/SERCOM4.1/I2SMCK1), U4.3
/D14: U3.25 (PB12/I12/SERCOM4.0/I2SCK1), U4.2
/D15: U3.60 (PB31/I15/SERCOM5.0), U4.32
/D16: U3.51 (PA27/I11), U4.27
/D17: U3.50 (PB23/I7/SERCOM1+5.3), U4.26
/D18: U3.49 (PB22/I6/SERCOM1+5.2), U4.25
/D+: U3.46 (PA25/I9/SERCOM3+5.3/D+), U4.24
/D-: U3.45 (PA24/I8/SERCOM3+5.2/D-), U4.23
/FLASH_CS: R1.2, U1.1 (SSEL), U3.24 (PB11/I11/SERCOM4.3/I2SFS1)
/FLASH_IO0: U1.5 (MOSI), U3.17 (PA08/I2C/AIN[8]/SERCOM0.0+2.1/I2SMCK)
/FLASH_IO1: U1.2 (MISO), U3.18 (PA09/I2C/I9/AIN[9]/SERCOM0.1+2.0/I2SFS0)
/FLASH_IO2: U1.3 (WP#/IO2), U3.19 (PA10/I10/AIN[10]/SERCOM0+2.2/I2SCK)
/FLASH_IO3: U1.7 (HOLD#/IO3), U3.20 (PA11/I11/AIN[11]/SERCOM0+2.3/I2SDO)
/FLASH_SCK: U1.6 (SCK), U3.23 (PB10/I10/SERCOM4.2/I2SDI)
/MISO: U3.31 (PA14/I14/SERCOM2+4.2), U4.8
/MOSI: U3.29 (PA12/I12/I2C/SERCOM2.0+4.1), U4.6
/RESET: C3.1, R3.1, R9.2, U3.52 (RESETN), U4.28
/SCK: U3.30 (PA13/I13/I2C/SERCOM2.1+4.0), U4.7
/SCL: R4.2, U3.64 (PB03/I3/AIN[15]/SERCOM5.1), U4.36
/SDA: R6.2, U3.63 (PB02/I2/AIN[14]/SERCOM5.0), U4.35
/SWCLK: R5.2, U3.57 (PA30/I14/SERCOM1.2/SWCLK), U4.29
/SWDIO: U3.58 (PA31/I15/SERCOM1.3/SWDIO), U4.30
/SWO: U3.59 (PB30/I14/SERCOM5.1/SWO), U4.31
GND: C1.1, C2.1, C3.2, C4.2, C5.2, C6.2, C7.2, C8.2, C9.2, C10.2, C11.1, C12.2, C13.1, C14.2, LED1.1 (K), LED2.1 (K), SW1.2, U1.4 (VSS), U2.2 (GND), U3.7 (GND), U3.22 (GND), U3.33 (GND), U3.47 (GND), U3.54 (GND), U3.65 (EP), U4.12, U4.37
unnamed: C1.2, U3.2 (PA01/EINT[1]/SERCOM1.1), Y1.P$1
unnamed: C2.2, U3.1 (PA00/EINT[0]/SERCOM1.0), Y1.P$2
unnamed: C6.1, C8.1, C9.1, U3.53 (VDDCORE)
unnamed: LED1.2 (A), R7.2
unnamed: LED2.2 (A), R8.2
unnamed: R3.2, SW1.1
VIN: C4.1, U2.1 (VIN), U2.3 (EN), U4.11

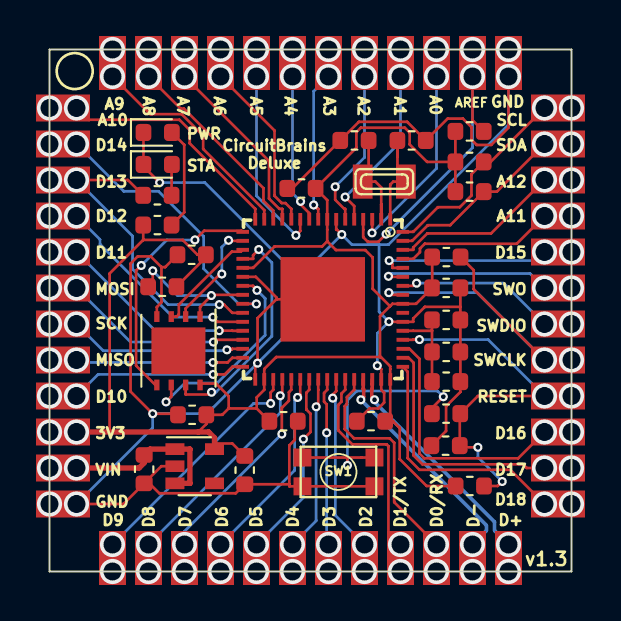
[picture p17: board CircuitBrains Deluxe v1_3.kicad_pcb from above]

Board: 2 copper layers, 29.0 x 29.0 mm, 31 parts (0 on the bottom side), 59 nets.

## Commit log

2019-12-12 Added CircuitBrains Deluxe v1_0 Project, Library and Footprints
    [CircuitBrains Deluxe v1_0-B_Cu.gbr, CircuitBrains Deluxe v1_0-B_Mask.gbr, CircuitBrains Deluxe v1_0-B_Paste.gbr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]
2019-12-30 Added v1.3 Schematic and Board
    [CircuitBrains Deluxe v1_3-B_Cu.gbr, CircuitBrains Deluxe v1_3-B_Mask.gbr, CircuitBrains Deluxe v1_3-B_Paste.gbr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]
2019-12-30 Create Schematic v1_3.pdf
2019-12-30 Fix & footprint/library
    Fixed a deleted reference in kicad project file
    Added kicad footprint and library files for the module
2019-12-30 Added Interactive BOM
2020-01-18 Fixed silk label size on board
    [CircuitBrains Deluxe v1_3.kicad_pcb]
2020-02-24 Removed Deluxe 1.0
    [CircuitBrains Deluxe v1_0-B_Cu.gbr, CircuitBrains Deluxe v1_0-B_Mask.gbr, CircuitBrains Deluxe v1_0-B_Paste.gbr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]
2020-03-12 Added Test Jigs
    [CB Basic Test Jig v1_0.kicad_pcb, CB Basic Test Jig v1_0.sch, CB Deluxe Test Jig v1_0.kicad_pcb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]
2020-03-13 Added CircuitBrains Basic
    [CircuitBrains Basic v1_2.kicad_pcb, CircuitBrains Basic v1_2.sch]
2020-12-04 Updated docs & updated CB Basic board file to kicad 6 format
    [CircuitBrains Basic v1.2 BOM.xlsx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]
